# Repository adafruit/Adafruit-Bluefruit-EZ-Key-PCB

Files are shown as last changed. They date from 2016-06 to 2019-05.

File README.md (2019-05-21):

## Adafruit Bluefruit EZ Key PCB (Discontinued)
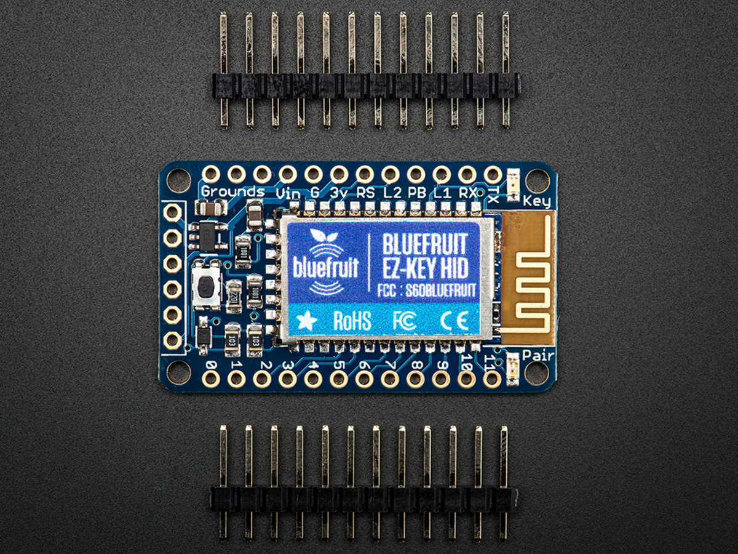
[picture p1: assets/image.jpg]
<a href="http://www.adafruit.com/products/1535"><br/>
Click here to purchase one from the Adafruit shop</a>

**These modules are currently discontinued**

Create your own wireless Bluetooth keyboard controller in an hour with the Bluefruit EZ-Key: it's the fastest, easiest and bestest Bluetooth controller. We spent years learning how to develop our own custom Bluetooth firmware, and coupled with our own BT module hardware, we've created the most Maker-friendly wireless you can get!

This breakout acts just like a BT keyboard, and works great with any BT-capable device: Mac, Windows, Linux, iOS, and Android. Power the module with 3-16VDC, and pair it to the computer, tablet or phone just as you would any other BT device. Now you can connect buttons from the 12 input pins, when a button is pressed, it sends a keypress to the computer. We pre-program the module to send the 4 arrow keys, return, space, 'w', 'a', 's', 'd', '1' and '2' by default. Advanced users can reprogram the module's keys using an FTDI or other Serial console cable, for any HID key report they desire.

PCB files for the Adafruit Bluefruit EZ Key, The format is EagleCAD schematic and board layout
- https://www.adafruit.com/product/1535

### License

Adafruit invests time and resources providing this open source design, please support Adafruit and open-source hardware by purchasing products from [Adafruit](https://www.adafruit.com)!

All text above must be included in any redistribution

Designed by Limor Fried/Ladyada for Adafruit Industries.
Creative Commons Attribution/Share-Alike, all text above must be included in any redistribution. 
See license.txt for additional information.

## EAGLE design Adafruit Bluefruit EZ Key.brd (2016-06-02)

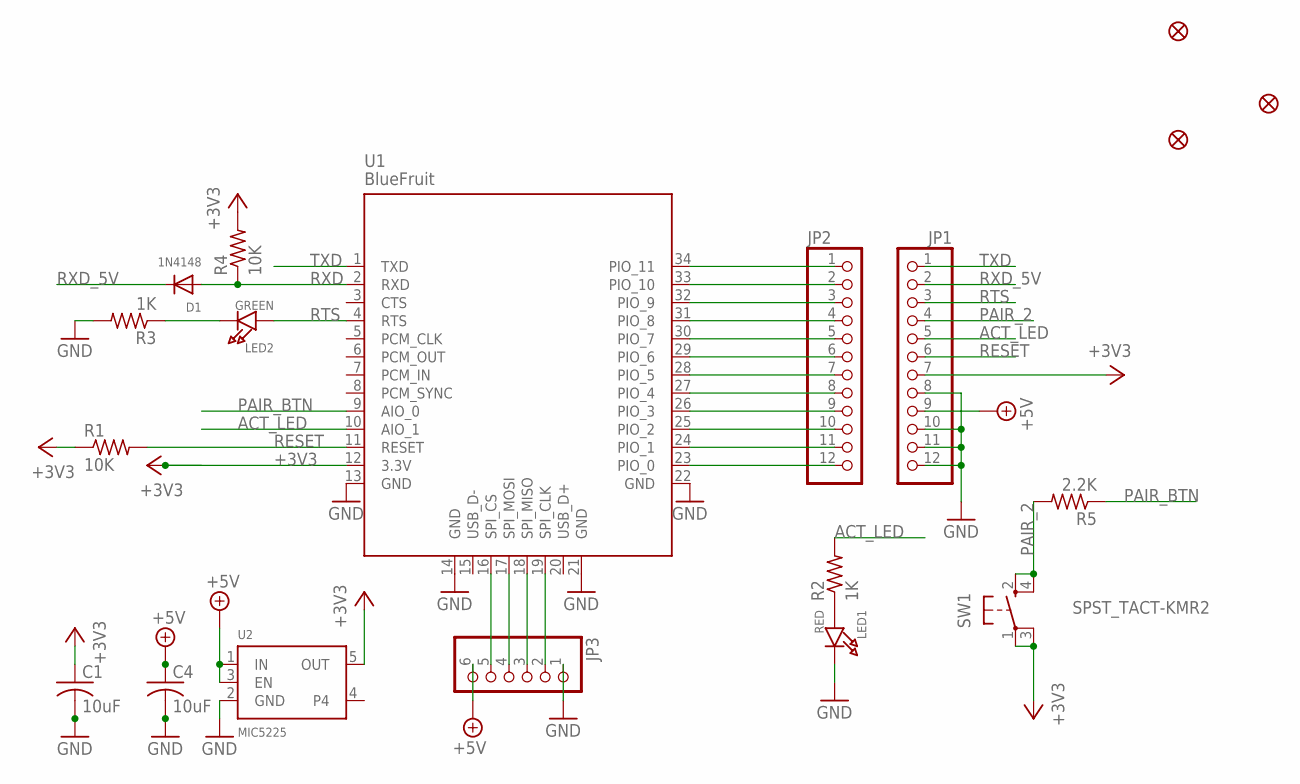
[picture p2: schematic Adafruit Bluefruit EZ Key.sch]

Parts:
C1, C4: 10uF; C0805
D1: 1N4148; SOD-323
FID1, FID2, FID3: FIDUCIAL""; FIDUCIAL_1MM
JP1, JP2: PINHD-1X12-CB; 1X12-CB
JP3: PINHD-1X6B; 1X06-BIG
LED1: RED; CHIPLED_0805_NOOUTLINE
LED2: GREEN; CHIPLED_0805_NOOUTLINE
R1, R4: 10K; R0805
R2, R3: 1K; R0805
R5: 2.2K; R0805
SW1: SPST_TACT-KMR2; KMR2
U1: BlueFruit; BLUETOOTH_MODULE
U2: MIC5225; SOT23-5

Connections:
+3V3: C1.1, JP1.7, R1.1, R4.2, SW1.1, SW1.3 (P1), U1.12 (3.3V), U2.5 (OUT)
+5V: C4.1, JP1.9, JP3.6, U2.1 (IN), U2.3 (EN)
ACT_LED: JP1.5, R2.2, U1.10 (AIO_1)
CLK: JP3.2, U1.19 (SPI_CLK)
CS: JP3.5, U1.16 (SPI_CS)
GND: C1.2, C4.2, JP1.8, JP1.10, JP1.11, JP1.12, JP3.1, LED1.C, R3.2, U1.13 (GND), U1.14 (GND), U1.21 (GND), U1.22 (GND), U2.2 (GND)
MISO: JP3.3, U1.18 (SPI_MISO)
MOSI: JP3.4, U1.17 (SPI_MOSI)
unnamed: JP2.5, U1.30 (PIO_7)
unnamed: LED1.A, R2.1
unnamed: LED2.C, R3.1
unnamed: JP2.12, U1.23 (PIO_0)
unnamed: JP2.11, U1.24 (PIO_1)
unnamed: JP2.10, U1.25 (PIO_2)
unnamed: JP2.9, U1.26 (PIO_3)
unnamed: JP2.8, U1.27 (PIO_4)
unnamed: JP2.7, U1.28 (PIO_5)
unnamed: JP2.6, U1.29 (PIO_6)
unnamed: JP2.4, U1.31 (PIO_8)
unnamed: JP2.3, U1.32 (PIO_9)
unnamed: JP2.2, U1.33 (PIO_10)
unnamed: JP2.1, U1.34 (PIO_11)
PAIR_2: JP1.4, R5.2, SW1.2 (S), SW1.4 (S1)
PAIR_BTN: R5.1, U1.9 (AIO_0)
RESET: JP1.6, R1.2, U1.11 (RESET)
RTS: JP1.3, LED2.A, U1.4 (RTS)
RXD: D1.A, R4.1, U1.2 (RXD)
RXD_5V: D1.C, JP1.2
TXD: JP1.1, U1.1 (TXD)

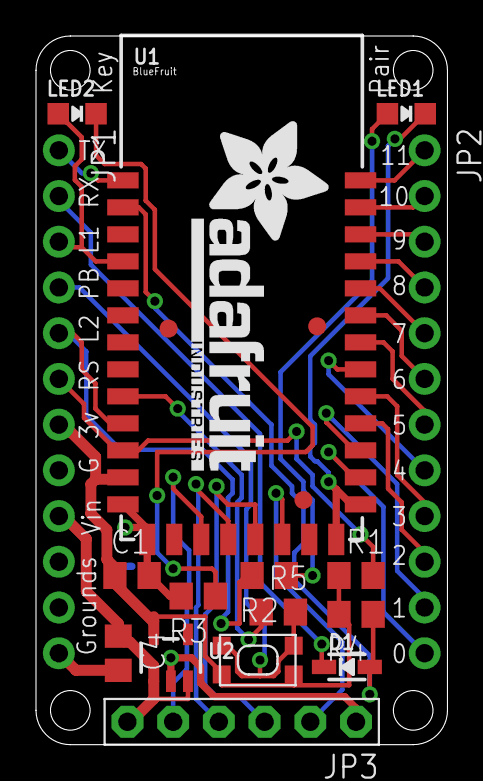
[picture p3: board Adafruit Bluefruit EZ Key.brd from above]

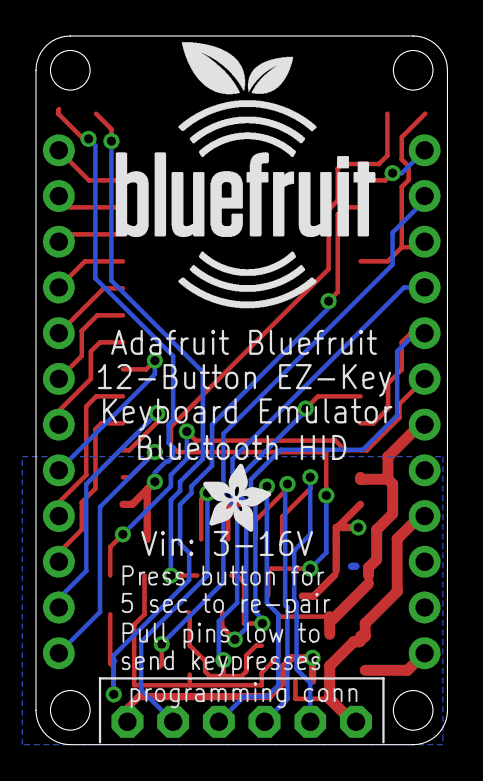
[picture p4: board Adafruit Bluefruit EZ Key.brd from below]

Board: 2 copper layers, 22.9 x 39.4 mm, 22 parts (2 on the bottom side), 29 nets.

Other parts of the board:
U$2: BLUEFRUITLOGO_150MM
U$3: ADAFRUIT_3.5MM
U$4: ADAFRUIT_TEXT_20MM
